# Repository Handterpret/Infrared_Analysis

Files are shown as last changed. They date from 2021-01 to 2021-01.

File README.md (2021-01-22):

# Infrared_Analysis

This repository contains code and documentation on how to collect data from infrared sensor around the wrist.

## Hardware needed

In this project I will use a clone of Arduino nano with ATMEGA328P and CH340 chip.

We will also use [infrared photodiodes](https://fr.rs-online.com/web/p/photodiodes/6547921/) and [infrared leds](https://fr.rs-online.com/web/p/led-ir/8768767/)
## prerequisite

If you are using CH340 chip (clone of arduino Nano) please download firmware to detect device in Arduino firmware:

Download and install firmware from : 
```
https://drive.google.com/drive/folders/1xc8l1gazUueeBtoYJpTShC4DcPErrreh
```
or other depending on the brand of your nano.

It should now appear fine in [Arduino IDE](https://www.arduino.cc/en/Main/OldSoftwareReleases) under tools => port

## Docker

For easier use you can use Docker:

```
docker build -t infrared_analysis ./Docker/
docker run -it --rm -v src:/opt/ infrared_analysis /bin/bash
```

WIP: To get data inside docker you need to mount usb serial (depends on host os)

## Test realised

### first test 1 led /1 diode
To check if your board/leds/photodiodes are ok, please see 
```
unit_test/Blink
```
wiring is as follow : 

- Led on GRND and D2 (cathode)

- Photodiode on 3.3V (cathode) and A0

Excpected output:

- Open serial monitor and you should see a low value then a high value repeatedly

### test with multiplexing

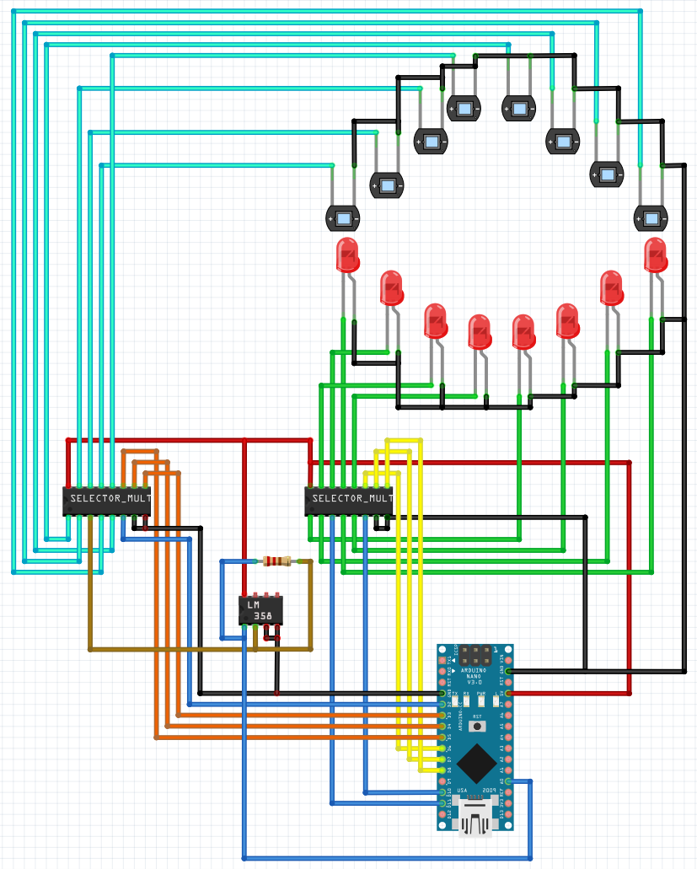
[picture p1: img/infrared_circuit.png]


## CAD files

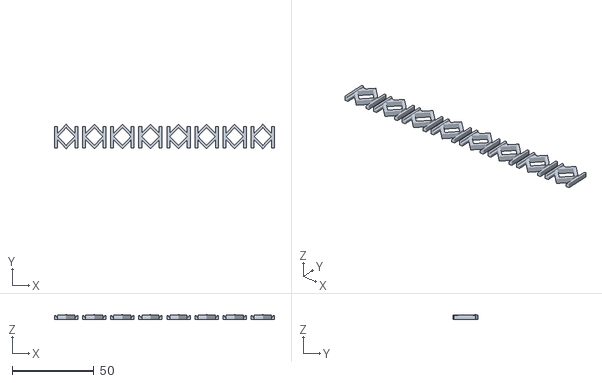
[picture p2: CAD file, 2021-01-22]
Bracelet_PFE_lien_flex v6.stl
134.3 x 15.0 x 2.80

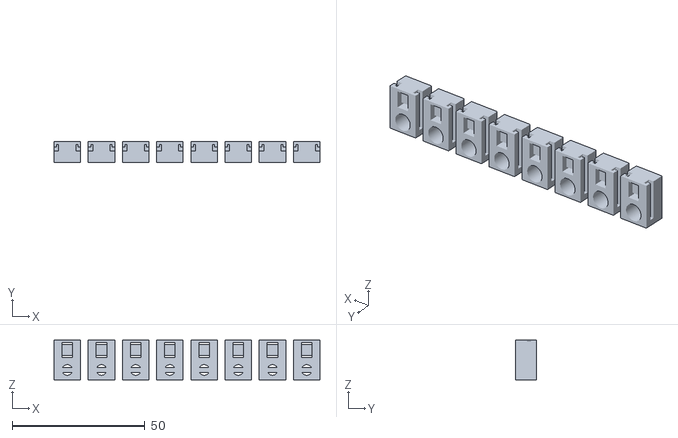
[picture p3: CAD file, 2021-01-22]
Bracelet_PFE_Receptacle v4.stl
100.0 x 7.80 x 15.0

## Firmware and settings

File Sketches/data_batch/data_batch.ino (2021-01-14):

int outputs[4] = {6,7,8}; // pins for selecting LED
int inputs[4] = {5,4,3}; // pins for selecting diode
int io_pin_diode = A0;
int inhib_diode = 2;
int io_pin = 11; // pin used for sending power to LEDs
int inhibit_pin = 10; // pin for turning off all LEDs
float diodes_values[9];
int capture_time = 1000; // capture time in milliseconds Warning: might overflow if capture time is too much 1000 seems just fine
int response_array[9][50]; 
int line_to_write = 0;
unsigned long start_time;
unsigned long loop_timer;
unsigned long message_num = 0;
void setup() {
  Serial.begin(9600);
  for(int ii;ii<3;ii++){
    pinMode(outputs[ii],OUTPUT); // output selection for LED control
  }


  for(int jj;jj<3;jj++){
    pinMode(inputs[jj],OUTPUT); // input selection for diode control
  }

  pinMode(inhibit_pin,OUTPUT); 
  digitalWrite(inhibit_pin,LOW); // raise high to disable all
  pinMode(inhib_diode,OUTPUT); 
  digitalWrite(inhib_diode,LOW); // raise high to disable all
  pinMode(io_pin,OUTPUT); // this controls the power sent to each LED
  digitalWrite(io_pin,HIGH); // send high to all LEDs when powered on
  pinMode(io_pin_diode,INPUT); // input of selected diode
  start_time = millis();
  line_to_write = 0;

}

void loop() {
  loop_timer = millis();
  if (loop_timer<start_time+capture_time){
    digitalWrite(inhibit_pin,LOW); // turn on led
    // looping through all 8 LEDs
    for (int jj=0;jj<8;jj++){
      // turn on LEDs based on bit conversion
      for(int ii=0;ii<3;ii++){
        digitalWrite(outputs[ii],bitRead(jj,ii));
      }
      delay(10);
      // looping through all 8 diodes
      for (int kk=0;kk<8;kk++){
        // turn on diodes based on bit conversion
        for(int ll=0;ll<3;ll++){
          digitalWrite(inputs[ll],bitRead(kk,ll));
        }
        response_array[kk][line_to_write] = analogRead(A0);
      }
        line_to_write++;
    }
    digitalWrite(inhibit_pin,HIGH); // turn off led
    //delay(10);
  }
  else{
    Serial.print("Message");Serial.print(message_num);
    Serial.print(" JSON{'IR':[");
    for(int i=0;i<line_to_write;i++){
      Serial.print("{'A':"); Serial.print(response_array[0][i]); Serial.print(", ");
      Serial.print("'B':"); Serial.print(response_array[1][i]); Serial.print(", ");
      Serial.print("'C':"); Serial.print(response_array[2][i]); Serial.print(", ");
      Serial.print("'D':"); Serial.print(response_array[3][i]); Serial.print(", ");
      Serial.print("'E':"); Serial.print(response_array[4][i]); Serial.print(", ");
      Serial.print("'F':"); Serial.print(response_array[5][i]); Serial.print(", ");
      Serial.print("'G':"); Serial.print(response_array[6][i]); Serial.print(", ");
      Serial.print("'H':"); Serial.print(response_array[7][i]); Serial.print("}");
      if(i!=line_to_write-1){
        Serial.print(", ");
        }
      // Serial.print("uT");
    }
    Serial.println("]}JSON");
    start_time = millis();
    line_to_write = 0;
    message_num++;
  }
}

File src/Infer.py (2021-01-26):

import serial
import argparse
import time
import json
import numpy as np
import os
import datetime
from tensorflow import keras
import tensorflow as tf

parser = argparse.ArgumentParser()

parser.add_argument("--serial", default="COM7", help="Serial port to connect to for instance COM3 on windows or /dev/ttyUSB0 on Linux")
parser.add_argument("-b", "--baud", help="Baud rate for reading serial port", default="9600")
parser.add_argument("--model_path", help="Where model is saved", default=".")
parser.add_argument("--dataset_path", help="Where dataset is saved", default=None)

args = parser.parse_args()

def InferIRData(serialport, baud, model_folder, dataset_path):
    if dataset_path:
        labels_name = os.listdir(dataset_path)
    ser = serial.Serial(serialport, baud)
    model = keras.models.load_model(model_folder)
    while True:
        print("Reading data from serial port")
        line = ser.readline()
        data = eval(str(line).split("JSON")[1])
        message_number = str(line).split('Message')[1].split('JSON')[0]
        print(f"Message : {message_number}")
        retrieved_data = ParseJsonData(data)
        if dataset_path:
            print(f"result : {labels_name[tf.argmax(model.predict(tf.expand_dims(retrieved_data, axis=0))[0])]}\n")
        else:
            print(f"result : {model.predict(tf.expand_dims(retrieved_data, axis=0))}\n")

def ParseJsonData(json_data):
    """Parse Json from arduino

    Args:
        json_data (str): look like {'IR':[{'A':3, 'B':0, 'C':0, 'D':0, 'E':1, 'F':4, 'G':0, 'H':0, ...},...]}

    Returns:
        [np.array]: 3D array of containing slices with shape (n,len_diode,len_diode)
        with len_diode corresponding to number of diode defined in json
    """
    data_names = [chr(letter) for letter in range(65,65+len(json_data["IR"][0]))] # except data to be A,B,C ...
    one_led_array = np.array([])
    one_slice_array = np.array([])
    slices_array = np.array([])

    for led_array in json_data["IR"]:
            for letter in data_names:
                one_led_array = np.append(one_led_array, int(led_array[letter]))
            if one_slice_array.size == 0:
                one_slice_array = np.expand_dims(one_led_array, axis=0)
            else:
                one_slice_array = np.append(one_slice_array ,[one_led_array], axis=0)
            if one_slice_array.shape == (len(data_names), len(data_names)):
                if slices_array.size == 0:
                    slices_array =  np.expand_dims(one_slice_array, axis=0)
                else:
                    slices_array = np.append(slices_array, [one_slice_array], axis=0)
                one_slice_array = np.array([])
            one_led_array = np.array([])
    return slices_array


if __name__ == "__main__":
    InferIRData(args.serial, args.baud, args.model_path, args.dataset_path)

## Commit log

2021-01-08 add img for wiring
2021-01-11 correct wiring
2021-01-12 fix circuit and add OP amp
2021-01-13 add Arduino sketch for data batch
2021-01-13 move sketch because Arduino want a folder with the same name as the sketch god why
2021-01-26 WIP add dataset path for easier print
2021-01-26 fix dataset parsing for inference
    [Infer.py]
